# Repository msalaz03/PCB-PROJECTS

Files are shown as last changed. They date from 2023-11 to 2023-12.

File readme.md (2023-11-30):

<h1 >Rudi 40-Pin Breakout</h1>
<p>As a member of the University of Guelph Robotics Team, I've taken on the exciting challenge of designing a 40-pin breakout board for the Rudi-NX. This marks a significant milestone as my first board design. Leveraging KiCad, I've implemented a PCB breakout for the GPIO Expansion Connector on the Rudi-NX, bringing together various communication protocols and input/output pins. </p>
<br>

<h1> Design + 3D Viewer</h1>
<p align = "center">
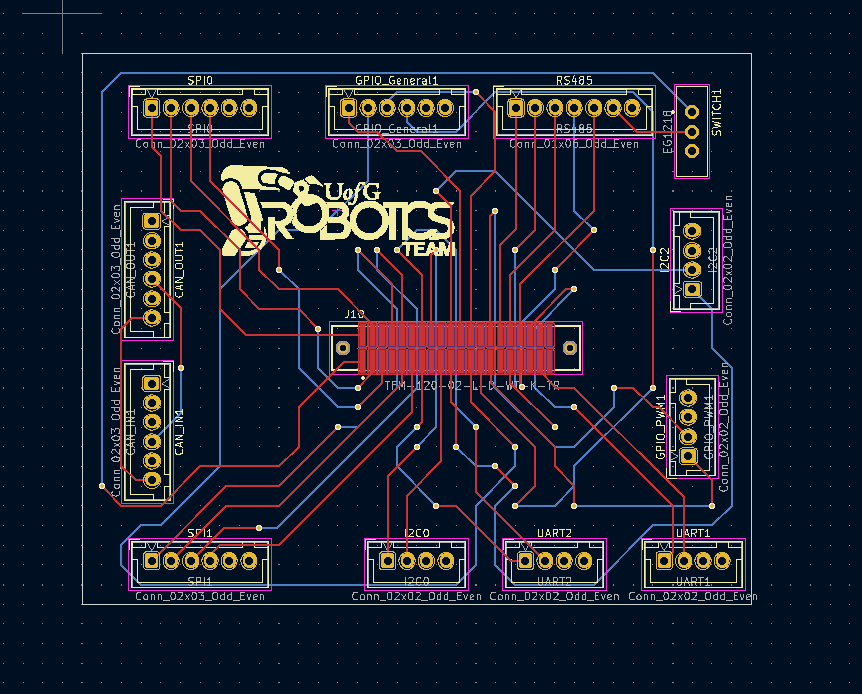
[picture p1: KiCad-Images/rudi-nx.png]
  
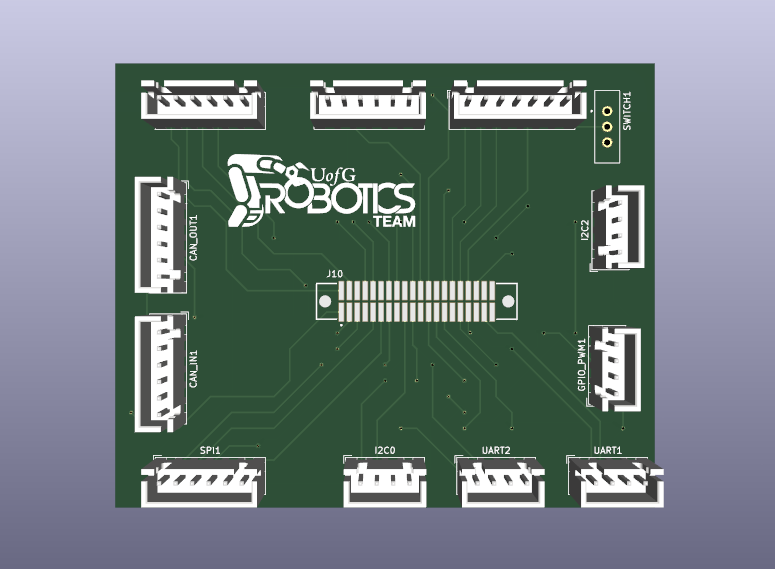
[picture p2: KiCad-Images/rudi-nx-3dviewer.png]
  
</p>
<br><br>

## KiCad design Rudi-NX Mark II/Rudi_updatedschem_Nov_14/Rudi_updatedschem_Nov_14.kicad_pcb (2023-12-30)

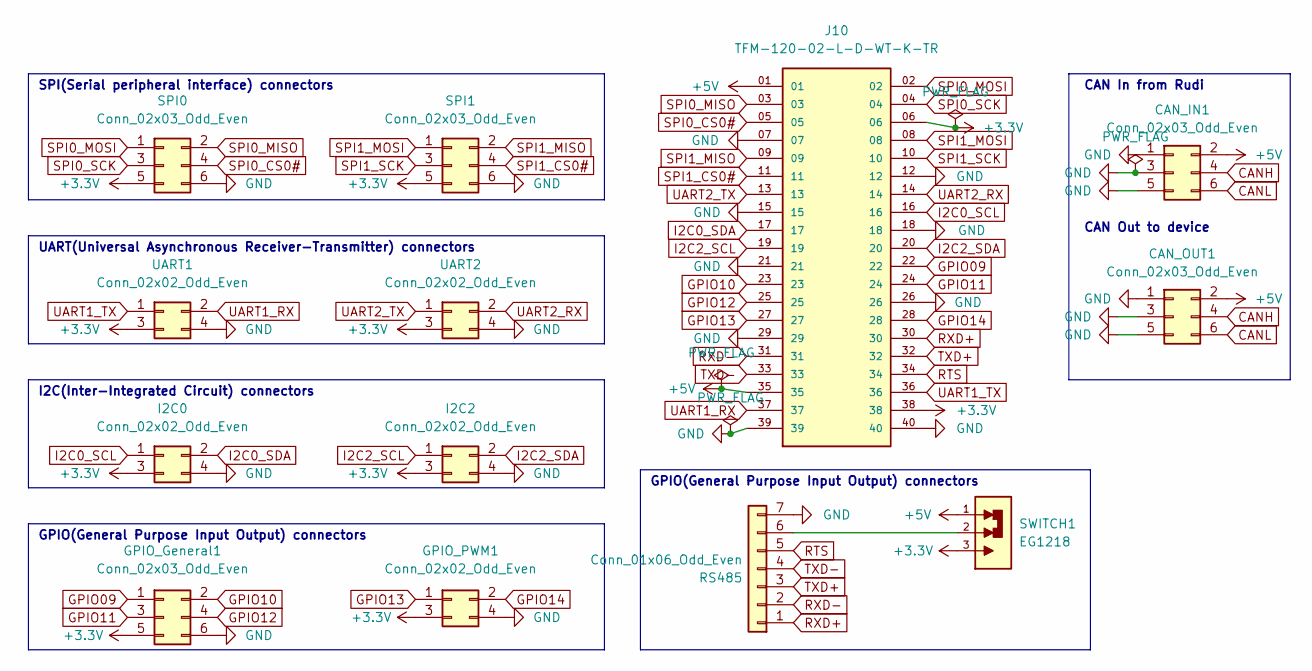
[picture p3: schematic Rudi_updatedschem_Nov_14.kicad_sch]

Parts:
CAN_IN1: Conn_02x03_Odd_Even; JST_XH_B6B-XH-A_1x06_P2.50mm_Vertical
CAN_OUT1: Conn_02x03_Odd_Even; JST_XH_B6B-XH-A_1x06_P2.50mm_Vertical
GPIO_General1: Conn_02x03_Odd_Even; JST_XH_B6B-XH-A_1x06_P2.50mm_Vertical
GPIO_PWM1: Conn_02x02_Odd_Even; JST_XH_B4B-XH-A_1x04_P2.50mm_Vertical
I2C0, I2C2: Conn_02x02_Odd_Even; JST_XH_B4B-XH-A_1x04_P2.50mm_Vertical
J10: TFM-120-02-L-D-WT-K-TR; SAMTEC_TFM-120-02-L-D-WT-K-TR; PARTREV Q
RS485: Conn_01x06_Odd_Even; JST_XH_B7B-XH-A_1x07_P2.50mm_Vertical
SPI0, SPI1: Conn_02x03_Odd_Even; JST_XH_B6B-XH-A_1x06_P2.50mm_Vertical
SWITCH1: EG1218; SW_EG1218
UART1, UART2: Conn_02x02_Odd_Even; JST_XH_B4B-XH-A_1x04_P2.50mm_Vertical

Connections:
+3.3V: GPIO_General1.5, GPIO_PWM1.3, I2C0.3, I2C2.3, J10.06, J10.38, SPI0.5, SPI1.5, SWITCH1.3, UART1.3, UART2.3
+5V: CAN_IN1.2, CAN_OUT1.2, J10.01, J10.35, SWITCH1.1
CANH: CAN_IN1.4, CAN_OUT1.4
CANL: CAN_IN1.6, CAN_OUT1.6
GND: CAN_IN1.1, CAN_IN1.3, CAN_IN1.5, CAN_OUT1.1, CAN_OUT1.3, CAN_OUT1.5, GPIO_General1.6, GPIO_PWM1.4, I2C0.4, I2C2.4, J10.07, J10.12, J10.15, J10.18, J10.21, J10.26, J10.29, J10.39, J10.40, RS485.7, SPI0.6, SPI1.6, UART1.4, UART2.4
GPIO09: GPIO_General1.1, J10.22
GPIO10: GPIO_General1.2, J10.23
GPIO11: GPIO_General1.3, J10.24
GPIO12: GPIO_General1.4, J10.25
GPIO13: GPIO_PWM1.1, J10.27
GPIO14: GPIO_PWM1.2, J10.28
I2C0_SCL: I2C0.1, J10.16
I2C0_SDA: I2C0.2, J10.17
I2C2_SCL: I2C2.1, J10.19
I2C2_SDA: I2C2.2, J10.20
unnamed: RS485.6, SWITCH1.2
RTS: J10.34, RS485.5
RXD+: J10.30, RS485.1
RXD-: J10.31, RS485.2
SPI0_CS0#: J10.05, SPI0.4
SPI0_MISO: J10.03, SPI0.2
SPI0_MOSI: J10.02, SPI0.1
SPI0_SCK: J10.04, SPI0.3
SPI1_CS0#: J10.11, SPI1.4
SPI1_MISO: J10.09, SPI1.2
SPI1_MOSI: J10.08, SPI1.1
SPI1_SCK: J10.10, SPI1.3
TXD+: J10.32, RS485.3
TXD-: J10.33, RS485.4
UART1_RX: J10.37, UART1.2
UART1_TX: J10.36, UART1.1
UART2_RX: J10.14, UART2.2
UART2_TX: J10.13, UART2.1

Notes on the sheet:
CAN Out to device
SPI(Serial peripheral interface) connectors
CAN In from Rudi
UART(Universal Asynchronous Receiver-Transmitter) connectors
GPIO(General Purpose Input Output) connectors
I2C(Inter-Integrated Circuit) connectors

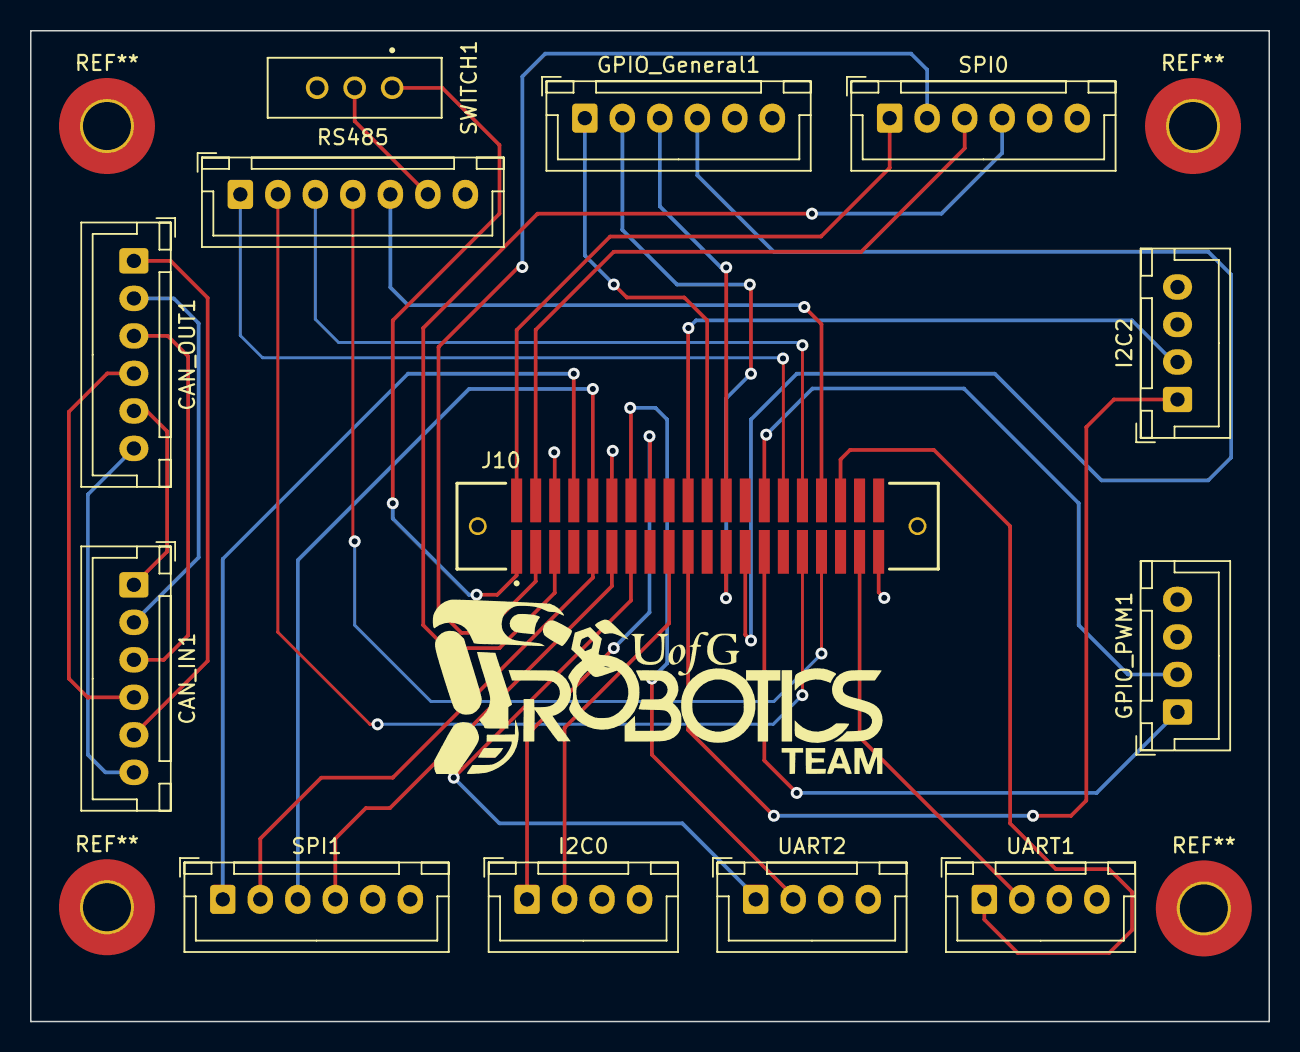
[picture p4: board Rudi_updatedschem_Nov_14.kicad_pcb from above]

Board: 4 copper layers, 82.6 x 66.0 mm, 13 parts (0 on the bottom side), 33 nets.
